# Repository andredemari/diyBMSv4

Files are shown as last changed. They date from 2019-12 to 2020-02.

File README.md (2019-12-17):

# ESP32 port of diyBMS v4

This is my port of Stuart Pittaway's excellent diyBMS ver 4 project

In this port the ESP8266 Controller has been replaced by an ESP32 and various changes have been made to support my local needs.
If you are looking for a straight port to ESP32 of Stuart's project, check out the 'Vanilla' branch.
Note: Because of the way serial ports work in ESP32, the Cell module firmware from this fork must be used. Cell modules programmed with the original firmware will not work.

Main changes are :-
* New Controller PCB design with ESP32 module ( a Lolin 32 Lite easily available on AliExpress)
* INA226 Current and Voltage monitor on PCB - INA226 is able to measure current through an external shunt on high or low side of battery. It supports battery voltages of up to 36V,
so since my battery is more than that I put the shunt halfway up the battery stack, and use a voltage divider to measure total battery voltage. INA226 is I2C connected to the ESP32.
https://www.ti.com/lit/ds/symlink/ina226.pdf
* I2C connector to attach to various fan controllers.
* PWM connector to signal discharge rate to my inverter.
* Serial interface to signal charge rate to my BST900 charger [BST900(https://github.com/delboy711/BST900)]
* Two connectors for Solid State Relays to power on/off charger and inverter.
* Management of Controller via MQTT commands from Node-Red.

Stuart's original README follows

##################################################################
 
Version 4 of the diyBMS

Do it yourself battery management system for Lithium ion battery packs/cells

If you are looking for version 3 of this project take a look here https://github.com/stuartpittaway/diyBMS

# TRAVIS-CI


# Videos on how to use and build

https://www.youtube.com/stuartpittaway

# WARNING

This is a DIY product/solution so don’t use this for safety critical systems or in any situation where there could be a risk to life.  

There is no warranty, it may not work as expected or at all.

The use of this project is done so entirely at your own risk.  It may involve electrical voltages which could kill - if in doubt, seek help.

The use of this project may not be compliant with local laws or regulations - if in doubt, seek help.

# License

This work is licensed under a Creative Commons Attribution-NonCommercial-ShareAlike 2.0 UK: England & Wales License.

https://creativecommons.org/licenses/by-nc-sa/2.0/uk/

You are free to:
* Share — copy and redistribute the material in any medium or format
* Adapt — remix, transform, and build upon the material
The licensor cannot revoke these freedoms as long as you follow the license terms.

Under the following terms:
* Attribution — You must give appropriate credit, provide a link to the license, and indicate if changes were made. You may do so in any reasonable manner, but not in any way that suggests the licensor endorses you or your use.
* Non-Commercial — You may not use the material for commercial purposes.
* ShareAlike — If you remix, transform, or build upon the material, you must distribute your contributions under the same license as the original.
* No additional restrictions — You may not apply legal terms or technological measures that legally restrict others from doing anything the license permits.

Notices:
You do not have to comply with the license for elements of the material in the public domain or where your use is permitted by an applicable exception or limitation.

No warranties are given. The license may not give you all of the permissions necessary for your intended use. For example, other rights such as publicity, privacy, or moral rights may limit how you use the material.

# Problem

A DIY Powerwall is the DIY construction of a pack of battery cells to create an energy store which can be used via inverters to power electrical items in the home. Generally cells are salvaged/second hand, and typically use Lithium 18650 cells.

Lithium batteries need to be kept at the same voltage level across a parallel pack. This is done by balancing each cell in the pack to raise or lower its voltage to match the others.

Existing balancing solutions are available in the market place, but at a relatively high cost compared to the cost of the battery bank, so this project is to design a low-cost, simple featured BMS/balancer.

# BMS Design

Design Goals: 
* Build upon my existing skill set and knowledge. 
* Building something that others can contribute to using regular standard libraries and off the shelf components.
* Build something that is inheriently safe
* Use platform.io to manage code and libraries
* Use Arduino based libraries and tools 
* Put everything on GITHUB
* Document it (always gets left to the end!)

# How it works

Controller provides human interface over Wifi/Web and also integrates with other systems like MQTT, emonCMS and Grafana.

Controller is esp8266-12e (NodeMCU v1) - although could be upgraded to ESP32 if really needed.

Controller should be able to take action on alerts/events to shut down inverters/chargers/fuses.

Each cell in a battery pack has a monitoring module.  This uses AVR ATTINY841 linked together by optoisolated serial ports for communication.

ATTINY841 provides:
* internal temperature monitoring
* external temperature monitoring
* Spare input/output for 3rd party use
* autonomous cell voltage balancing - it should still work even if controller is down

# How as v4 improved over v3?

* Code is better!
* Web interface no longer requires access to internet to download javascript libraries
* Controller provides outputs for integration with relay boards and switch gear
* Rules to control relay outputs
* Cell modules use ATTINY841 chip which provides more pins and lower power usage
* Removal of 3.3v regulator and ADUM chips lowers current usage significantly
* v3 module uses 10-12mA current constantly and v4 uses <1mA
* Dual temperature monitoring board + cells

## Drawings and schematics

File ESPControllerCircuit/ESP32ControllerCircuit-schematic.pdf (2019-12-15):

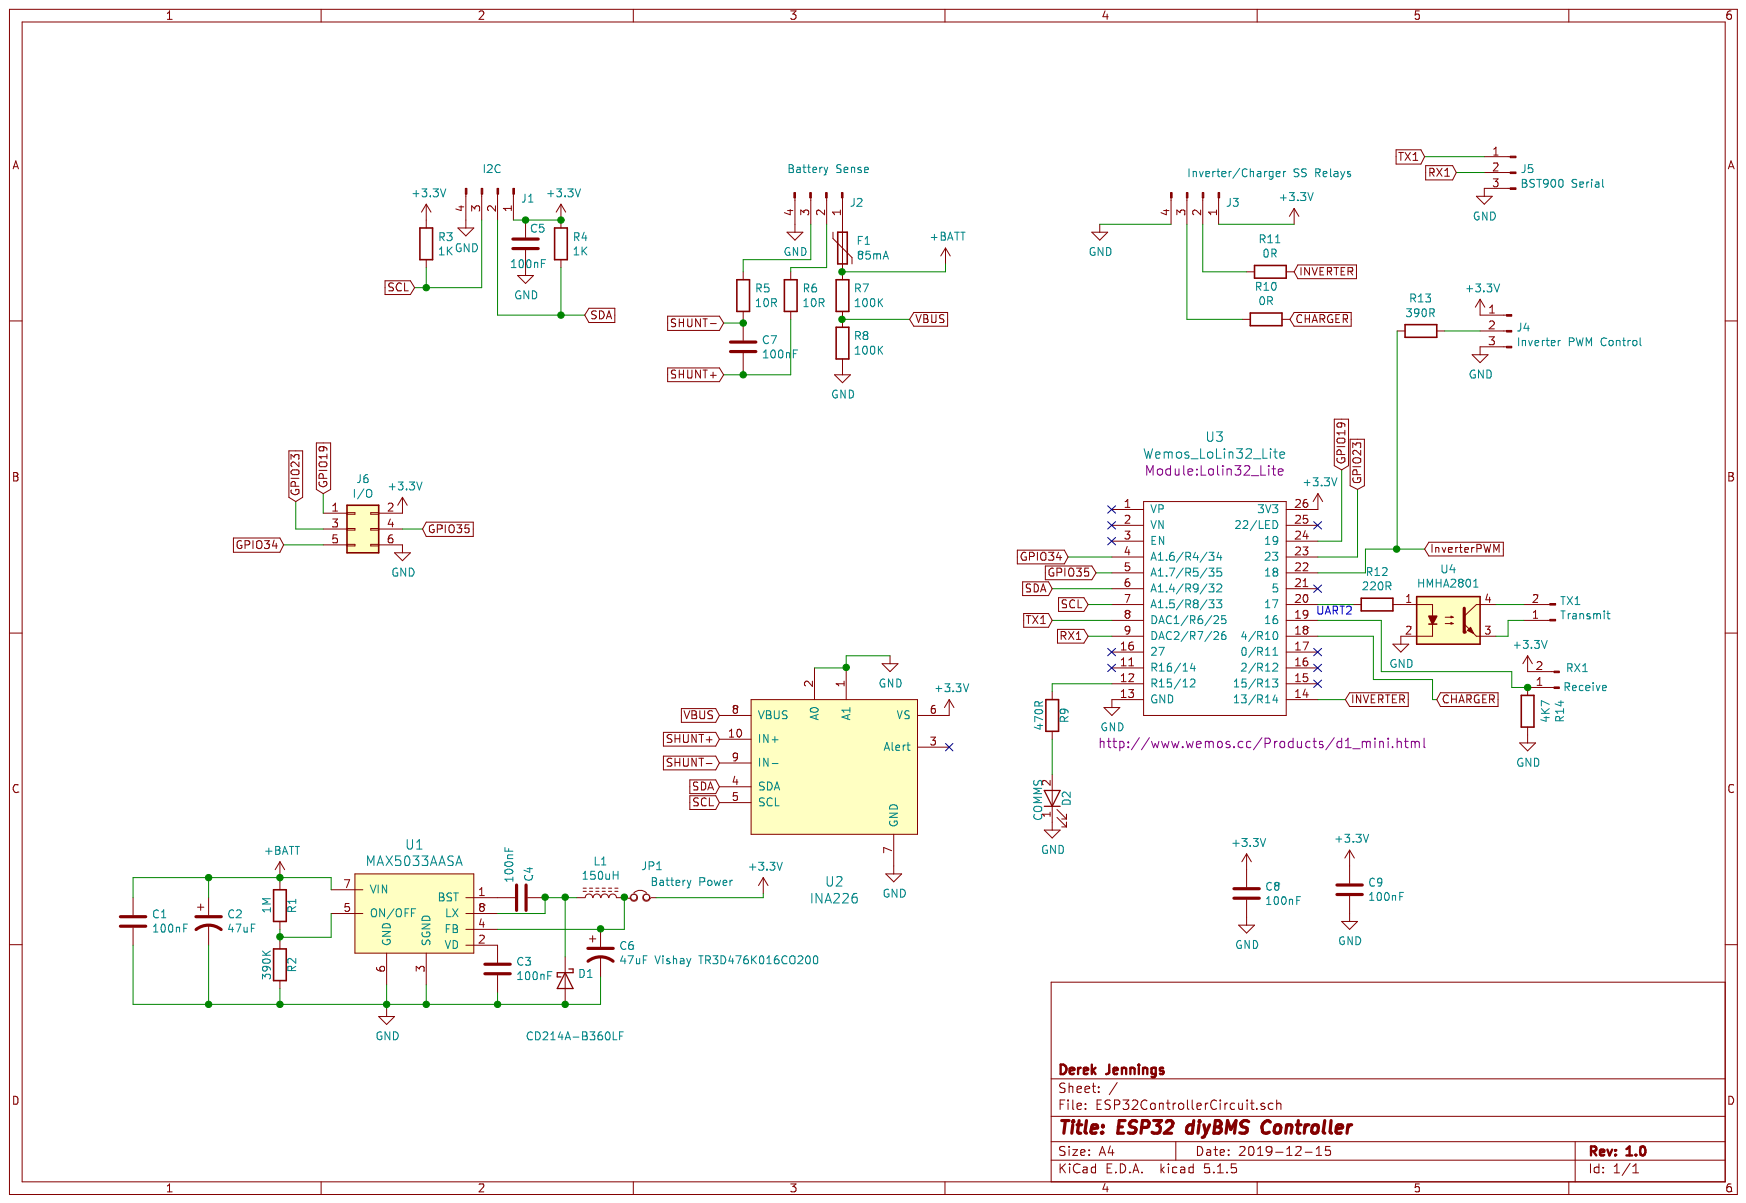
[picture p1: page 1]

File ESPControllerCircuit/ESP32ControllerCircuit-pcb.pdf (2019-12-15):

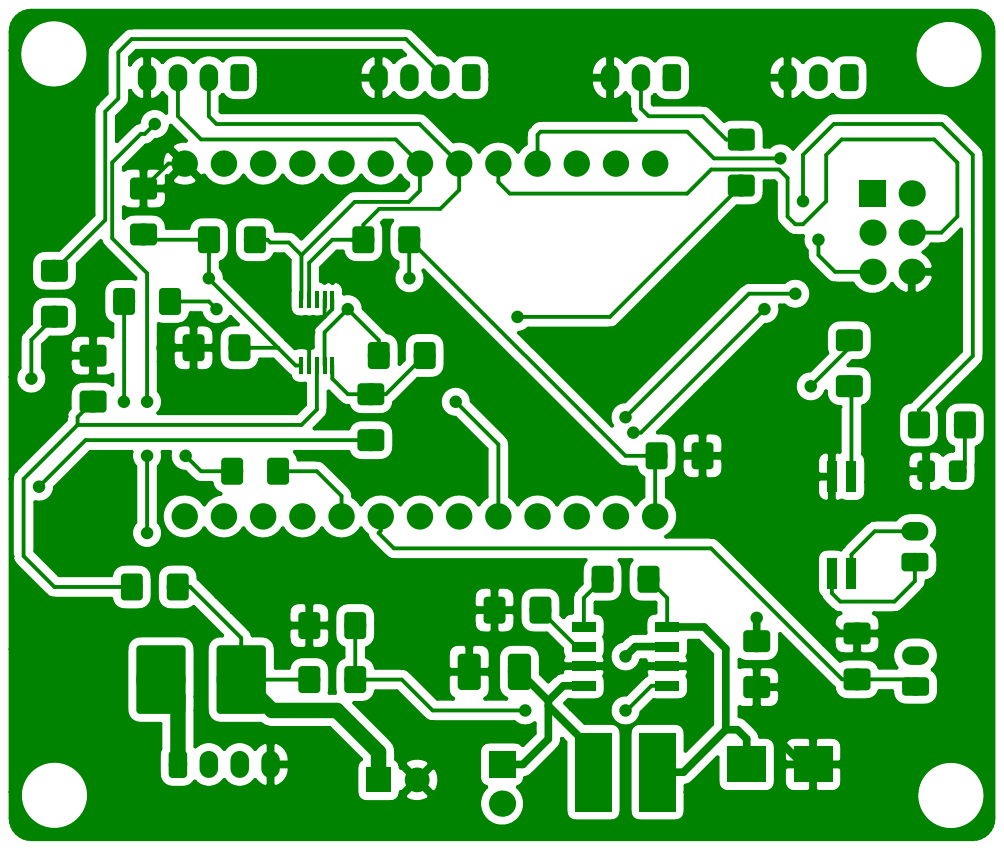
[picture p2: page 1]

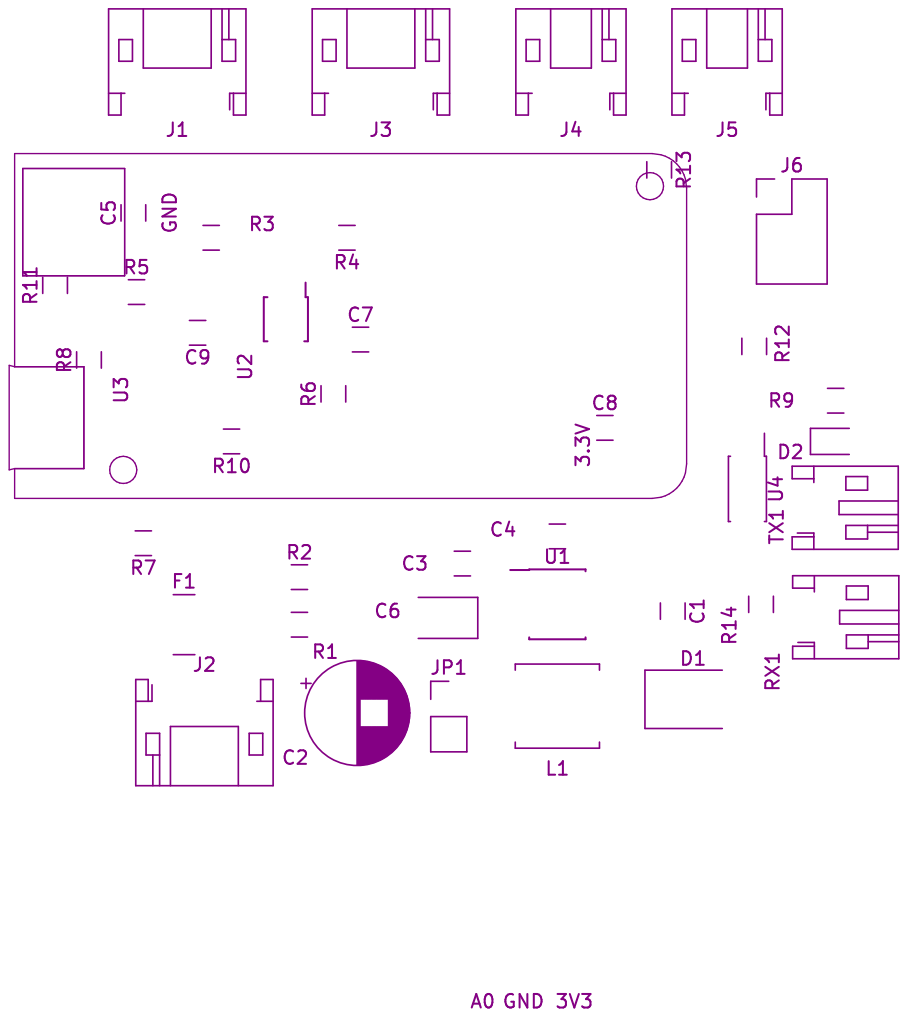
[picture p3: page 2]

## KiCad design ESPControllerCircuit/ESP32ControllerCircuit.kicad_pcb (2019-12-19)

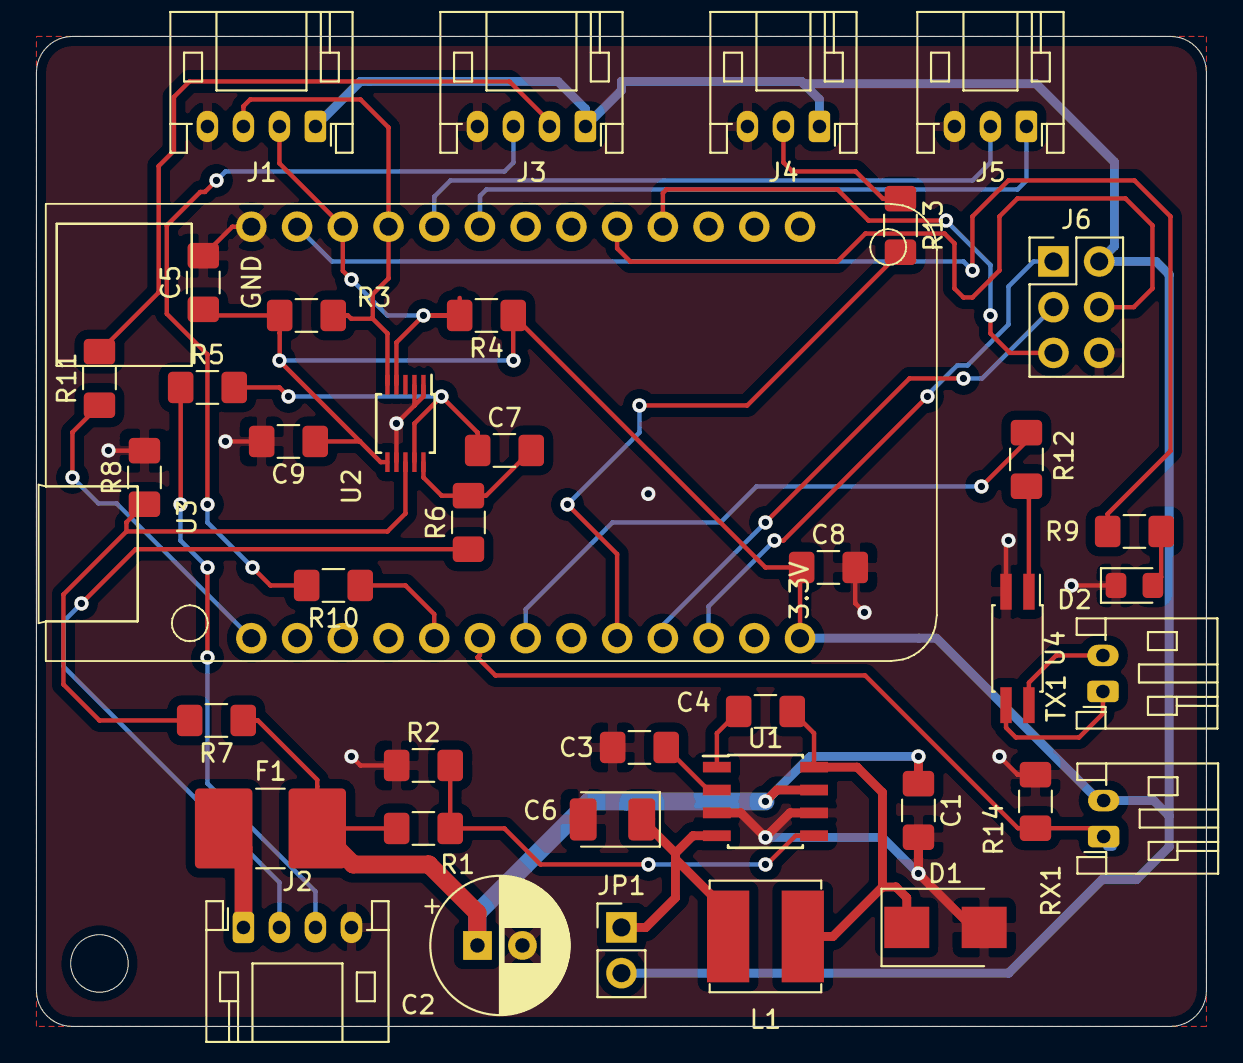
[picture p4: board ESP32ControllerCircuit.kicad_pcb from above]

Board: 2 copper layers, 65.0 x 55.0 mm, 40 parts (0 on the bottom side), 35 nets.

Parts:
C1, C3, C4, C5, C7, C8, C9: 100nF; C_1206_3216Metric_Pad1.42x1.75mm_HandSolder
C2: 47uF; CP_Radial_D7.5mm_P2.50mm
C6: 47uF Vishay TR3D476K016CO200; CP_EIA-3528-12_Kemet-T_Pad1.50x2.35mm_HandSolder
D1: CD214A-B360LF; D_SMB
D2: COMMS; LED_0805_2012Metric_Pad1.15x1.40mm_HandSolder
F1: 85mA; R_2816_7142Metric_Pad3.20x4.45mm_HandSolder
J1: I2C; JST_PH_S4B-PH-K_1x04_P2.00mm_Horizontal
J2: Battery Sense; JST_PH_S4B-PH-K_1x04_P2.00mm_Horizontal
J3: Inverter/Charger SS Relays; JST_PH_S4B-PH-K_1x04_P2.00mm_Horizontal
J4: Inverter PWM Control; JST_PH_S3B-PH-K_1x03_P2.00mm_Horizontal
J5: BST900 Serial; JST_PH_S3B-PH-K_1x03_P2.00mm_Horizontal
J6: I/O; PinHeader_2x03_P2.54mm_Vertical
JP1: Battery Power; PinHeader_1x02_P2.54mm_Vertical
L1: 150uH; L_Bourns_SRN6045TA
R1: 1M; R_1206_3216Metric_Pad1.42x1.75mm_HandSolder
R2: 390K; R_1206_3216Metric_Pad1.42x1.75mm_HandSolder
R3, R4: 1K; R_1206_3216Metric_Pad1.42x1.75mm_HandSolder
R5, R6: 10R; R_1206_3216Metric_Pad1.42x1.75mm_HandSolder
R7, R8: 100K; R_1206_3216Metric_Pad1.42x1.75mm_HandSolder
R9: 470R; R_1206_3216Metric_Pad1.42x1.75mm_HandSolder
R10, R11: 0R; R_1206_3216Metric_Pad1.42x1.75mm_HandSolder
R12: 220R; R_1206_3216Metric_Pad1.42x1.75mm_HandSolder
R13: 390R; R_1206_3216Metric_Pad1.42x1.75mm_HandSolder
R14: 4K7; R_1206_3216Metric_Pad1.42x1.75mm_HandSolder
RX1: Receive; JST_PH_S2B-PH-K_1x02_P2.00mm_Horizontal
TX1: Transmit; JST_PH_S2B-PH-K_1x02_P2.00mm_Horizontal
U1: MAX5033AASA; SOIC-8_3.9x4.9mm_P1.27mm
U2: INA226; TSSOP-10_3x3mm_P0.5mm
U3: Wemos_LoLin32_Lite; Lolin32_Lite
U4: HMHA2801; SO-4_4.4x2.3mm_P1.27mm

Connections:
+3V3: C5.1, C8.1, C9.1, J1.1, J3.1, J4.1, J6.2, JP1.2, R3.1, R4.1, RX1.2, U2.6, U3.26
+BATT: C1.1, C2.1, F1.2, R1.2, R7.1, U1.7
CHARGER: R10.1, U3.18
GND: C1.2, C2.2, C3.2, C5.2, C6.2, C8.2, C9.2, D1.2, D2.1, J1.4, J2.4, J3.4, J4.3, J5.3, J6.6, R2.1, R8.2, R14.1, U1.3, U1.6, U2.1, U2.2, U2.7, U3.13, U4.2
GPIO19: J6.1, U3.24
GPIO23: J6.3, U3.23
GPIO34: J6.5, U3.4
GPIO35: J6.4, U3.5
INVERTER: R11.1, U3.14
InverterPWM: R13.2, U3.22
unnamed: C3.1, U1.2
unnamed: C4.1, D1.1, L1.1, U1.8
unnamed: C4.2, U1.1
unnamed: C6.1, JP1.1, L1.2, U1.4
unnamed: D2.2, R9.1
unnamed: F1.1, J2.1
unnamed: J2.2, R6.1
unnamed: J2.3, R5.1
unnamed: J3.2, R11.2
unnamed: J3.3, R10.2
unnamed: J4.2, R13.1
unnamed: R1.1, R2.2, U1.5
unnamed: R9.2, U3.12
unnamed: R12.1, U4.1
unnamed: R12.2, U3.20
unnamed: R14.2, RX1.1, U3.19
unnamed: TX1.1, U4.3
unnamed: TX1.2, U4.4
RX1: J5.2, U3.9
SCL: J1.3, R3.2, U2.5, U3.10
SDA: J1.2, R4.2, U2.4, U3.11
SHUNT+: C7.2, R6.2, U2.10
SHUNT-: C7.1, R5.2, U2.9
TX1: J5.1, U3.8
VBUS: R7.2, R8.1, U2.8

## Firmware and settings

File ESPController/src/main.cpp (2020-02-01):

/*

 ____  ____  _  _  ____  __  __  ___    _  _  __
(  _ \(_  _)( \/ )(  _ \(  \/  )/ __)  ( \/ )/. |
 )(_) )_)(_  \  /  ) _ < )    ( \__ \   \  /(_  _)
(____/(____) (__) (____/(_/\/\_)(___/    \/   (_)

  (c) 2017/18/19 Stuart Pittaway

  This is the code for the controller - it talks to the V4 cell modules over isolated serial bus

  This code runs on ESP-8266-12E (NODE MCU 1.0) and compiles with Arduino 1.8.5 environment
  Modified by Derek Jennings to run on ESP32 compiled on platformio


   PINS
   GREEN_LED  = ESP32 GPIO 12
   i2c SDA   = ESP32 GPIO 32
   i2c SCL   = ESP32 GPIO 33
   switch to ground (reset WIFI configuration on power up) = ESP32 GPIO 34
   Interrupt in from PCF8574  = ESP32 GPIO 35
   PWM output to inverter = ESP32 GPIO 18
   ESP32_RELAY1 (CHARGER) 4       //GPIO PINS of ESP32 Relay outputs
   ESP32_RELAY2 (INVERTER) 13
   ESP32_RELAY3 19      //On expansion header
   Serial 0 DEBUG
   Serial 1  Charger Controller
   Serial 2   To Cell Modules


   DIAGRAM
   https://www.hackster.io/Aritro/getting-started-with-esp-nodemcu-using-arduinoide-aa7267
*/


#include <Arduino.h>
//#include <ESP8266WiFi.h>
#include <WiFi.h>
//#include <ESP8266mDNS.h>
#include <ESPmDNS.h>
#include <Hash.h>
#include <ESPAsyncWebServer.h>
#include <AsyncMqttClient.h>
#include <PacketSerial.h>
#include <cppQueue.h>
#include <Ticker.h>
#include <pcf8574_esp.h>
#include <Wire.h>
#include <ArduinoOTA.h>
#include "mqtt.h"

//Debug flags for ntpclientlib
#define DBG_PORT Serial
#define DEBUG_NTPCLIENT

#include <TimeLib.h>
#include <NtpClientLib.h>

#include "defines.h"

bool PCF8574Enabled;
volatile bool emergencyStop=false;
bool rule_outcome[RELAY_RULES];

uint16_t ConfigHasChanged=0;
diybms_eeprom_settings mysettings;

AsyncWebServer server(80);

bool server_running=false;
bool wifiFirstConnected = false;
bool NTPsyncEventTriggered = false; // True if a time even has been triggered
NTPSyncEvent_t ntpEvent; // Last triggered event

uint8_t packetType=0;
uint8_t previousRelayState[RELAY_TOTAL];
bool previousRelayPulse[RELAY_TOTAL];

//PCF8574P has an i2c address of 0x38 instead of the normal 0x20
PCF857x pcf8574(0x38, &Wire);

//Map GPIO pins to relays
uint8_t ESP32_relays[RELAY_TOTAL] = {ESP32_RELAY1, ESP32_RELAY2, ESP32_RELAY3};
volatile bool PCFInterruptFlag = false;

void ICACHE_RAM_ATTR PCFInterrupt() {
  if ((pcf8574.read8() & B00010000)==0) {
      //Emergency Stop (J1) has triggered
      emergencyStop=true;
  }
}

//This large array holds all the information about the modules
//up to 4x16
CellModuleInfo cmi[maximum_bank_of_modules][maximum_cell_modules];
uint8_t numberOfModules[maximum_bank_of_modules];



#include "crc16.h"

#include "settings.h"
#include "SoftAP.h"
#include "DIYBMSServer.h"
#include "PacketRequestGenerator.h"
#include "PacketReceiveProcessor.h"

// Instantiate queue to hold packets ready for transmission
Queue	requestQueue(sizeof(packet), 16, FIFO);

PacketRequestGenerator prg=PacketRequestGenerator(&requestQueue);

PacketReceiveProcessor receiveProc=PacketReceiveProcessor();

#define framingmarker (uint8_t)0x00

PacketSerial_<COBS, framingmarker, 128> myPacketSerial;

mqttProc mqt;

volatile bool waitingForReply=false;

//WiFiEventHandler wifiConnectHandler;
//WiFiEventHandler wifiDisconnectHandler;

Ticker myTimerRelay;

Ticker myTimer;
Ticker myTransmitTimer;
Ticker wifiReconnectTimer;
Ticker mqttReconnectTimer;
Ticker myTimerSendMqttPacket;
Ticker myTimerSendInfluxdbPacket;

Ticker myTimerSwitchPulsedRelay;
Ticker mqttTimeout;         //Times out if mqtt communication lost with node-red

uint16_t sequence=0;

AsyncMqttClient mqttClient;

void dumpPacketToDebug(packet *buffer) {
  Serial.print(buffer->address,HEX);
  Serial.print('/');
  Serial.print(buffer->command,HEX);
  Serial.print('/');
  Serial.print(buffer->sequence,HEX);
  Serial.print('=');
  for (size_t i = 0; i < maximum_cell_modules; i++)
  {
    Serial.print(buffer->moduledata[i],HEX);
    Serial.print(" ");
  }
  Serial.print(" =");
  Serial.print(buffer->crc,HEX);
}

uint16_t minutesSinceMidnight() {
  return (hour() * 60) + minute();
}

void processSyncEvent (NTPSyncEvent_t ntpEvent) {
    if (ntpEvent < 0) {
        Serial.printf ("Time Sync error: %d\n", ntpEvent);
        if (ntpEvent == noResponse)
            Serial.println ("NTP server not reachable");
        else if (ntpEvent == invalidAddress)
            Serial.println ("Invalid NTP server address");
        else if (ntpEvent == errorSending)
            Serial.println ("Error sending request");
        else if (ntpEvent == responseError)
            Serial.println ("NTP response error");
    } else {
        if (ntpEvent == timeSyncd) {
            Serial.print ("Got NTP time: ");
            Serial.println (NTP.getTimeDateString (NTP.getLastNTPSync()));
        }
    }
}

void mqtlostcomms() {   //callback when mqtt timeout timer expires
  mqt.lostcomms();
}

void onPacketReceived(const uint8_t* receivebuffer, size_t len)
{
  //Note that this function gets called frequently with zero length packets
  //due to the way the modules operate

  if (len==sizeof(packet)) {
    // Process decoded incoming packet
    Serial.print("R:");
    dumpPacketToDebug((packet*)receivebuffer);

    if (!receiveProc.ProcessReply(receivebuffer,sequence)) {
      Serial.println("** FAILED PROCESS REPLY **");
    }

    //We received a packet (although may have been an error)
    waitingForReply=false;

    Serial.println();
  }
}

void timerTransmitCallback() {
  //Don't send another message until we have received reply from the last one
  //this slows the transmit process down a lot so potentially need to look at a better
  //way to do this and also keep track of missing messages replies for error tracking
  if (waitingForReply) {
    //Serial.print('E');Serial.print(receiveProc.commsError);

    //Increment the counter to watch for complete comms failures
    receiveProc.commsError++;

    //After 5 attempts give up and send another packet
    if (receiveProc.commsError>10) {
      waitingForReply=false;
      receiveProc.totalMissedPacketCount++;
    } else {
        return;
    }
  }

  //Called every second to transmit anything that remains in the transmit queue
  if (!requestQueue.isEmpty()) {
    packet transmitBuffer;

    GREEN_LED_ON;

    //Wake up the connected cell module from sleep
    Serial2.write(framingmarker);
    delay(10);

    requestQueue.pop(&transmitBuffer);
    sequence++;
    transmitBuffer.sequence=sequence;
    transmitBuffer.crc=CRC16::CalculateArray((uint8_t*)&transmitBuffer, sizeof(packet) - 2);
    myPacketSerial.send((byte*)&transmitBuffer, sizeof(transmitBuffer));

    waitingForReply=true;

    Serial.print("S:");
    dumpPacketToDebug(&transmitBuffer);

    Serial.print("/Q:");
    Serial.print(requestQueue.getCount());
    Serial.print(" # ");

    GREEN_LED_OFF;
  }
}

void ProcessRules() {

//Runs the rules and populates rule_outcome array with true/false for each rule

  uint32_t packvoltage[4];

  packvoltage[0]=0;
  packvoltage[1]=0;
  packvoltage[2]=0;
  packvoltage[3]=0;

  for (int8_t r = 0; r < RELAY_RULES; r++)
  {
    rule_outcome[r]=false;
  }

  //If we have a communications error
  if (emergencyStop) {
    rule_outcome[0]=true;
  }

  //If we have a communications error
  if (receiveProc.commsError > 2) {
    rule_outcome[1]=true;
  }

  //Loop through cells
  for (int8_t bank = 0; bank < mysettings.totalNumberOfBanks; bank++)
  {
    for (int8_t i = 0; i < numberOfModules[bank]; i++) {

      packvoltage[bank]+=cmi[bank][i].voltagemV;

      if (cmi[bank][i].voltagemV > mysettings.rulevalue[2]) {
          //Rule 2 - Individual cell over voltage
          rule_outcome[2]=true;
      }

      if (cmi[bank][i].voltagemV < mysettings.rulevalue[3]) {
          //Rule 3 - Individual cell under voltage (mV)
          rule_outcome[3]=true;
      }

      if ((cmi[bank][i].externalTemp!=-40) && (cmi[bank][i].externalTemp > mysettings.rulevalue[4])) {
          //Rule 4 - Individual cell over temperature (external probe)
          rule_outcome[4]=true;
      }
    }
  }

  //Combine the voltages if we need to
  if (mysettings.combinationParallel==false) {
    packvoltage[0]+=packvoltage[1]+packvoltage[2]+packvoltage[3];
    packvoltage[1]=0;
    packvoltage[2]=0;
    packvoltage[3]=0;
  }

  for (int8_t bank = 0; bank < mysettings.totalNumberOfBanks; bank++)
  {
    if (packvoltage[bank] > mysettings.rulevalue[5]) {
      //Rule 5 - Pack over voltage (mV)
      rule_outcome[5]=true;
    }

    if (packvoltage[bank] < mysettings.rulevalue[6]) {
      //Rule 6 - Pack under voltage (mV)
      rule_outcome[6]=true;
    }
  }

  rule_outcome[7]= mqt.mqttRelayControl;          //Status of MQTT control
  if(mqt.active) {
    mqttTimeout.detach();
    mqttTimeout.attach(120, mqtlostcomms);      //Reset the timeout
    mqt.active=false;   //clear the flag. It will be set again when another command arrives
  }

  //Time based rules 8 and 9 (Rule 7 is MQTT)
  if (minutesSinceMidnight() >= mysettings.rulevalue[8]) {
    rule_outcome[8]=true;
  }
  if (minutesSinceMidnight() >= mysettings.rulevalue[9]) {
    rule_outcome[9]=true;
  }

}

void timerSwitchPulsedRelay() {
  //Set defaults based on configuration
  for (int8_t y = 0; y<RELAY_TOTAL; y++)
  {
    if (previousRelayPulse[y]) {
        //We now need to rapidly turn off the relay after a fixed period of time (pulse mode)
        //However we leave the relay and previousRelayState looking like the relay has triggered (it has!)
        //to prevent multiple pulses being sent on each rule refresh
        if(PCF8574Enabled) pcf8574.write(y, previousRelayState[y]==HIGH ? LOW:HIGH);
          else digitalWrite(ESP32_relays[y], previousRelayState[y]==HIGH ? LOW:HIGH);

      previousRelayPulse[y]=false;
    }
  }

  //This only fires once
  myTimerSwitchPulsedRelay.detach();
}


void timerProcessRules() {

  //Run the rules
  ProcessRules();

  // DO NOTE: When you write LOW to a pin on a PCF8574 it becomes an OUTPUT.
  // It wouldn't generate an interrupt if you were to connect a button to it that pulls it HIGH when you press the button.
  // Any pin you wish to use as input must be written HIGH and be pulled LOW to generate an interrupt.

  Serial.print("Rules:");
  for (int8_t r = 0; r < RELAY_RULES; r++)
  {
    Serial.print(rule_outcome[r]);
  }
  Serial.print(" = ");

  uint8_t relay[RELAY_TOTAL];

  //Set defaults based on configuration
  for (int8_t y = 0; y<RELAY_TOTAL; y++)
  {
    if(PCF8574Enabled) relay[y]=  mysettings.rulerelaydefault[y]==RELAY_ON ? LOW:HIGH;    //Inverse logic
    else relay[y]=  mysettings.rulerelaydefault[y]==RELAY_ON ? HIGH:LOW;
  }

  //Test the rules (in reverse order)
  for (int8_t n = RELAY_RULES-1; n>=0; n--)
  {

    if (rule_outcome[n]==true) {

      for (int8_t y = 0; y<RELAY_TOTAL; y++)
      {
        if (n==7) {         //MQTT rule
          relay[y] = mqt.mqttRelay[y];      //Set relays
          continue;
        }
        //Dont change relay if its set to ignore/X
        if (mysettings.rulerelaystate[n][y]!=RELAY_X) {
            //Logic is inverted on the PCF chip
            if (mysettings.rulerelaystate[n][y]==RELAY_ON) {
              relay[y]=(PCF8574Enabled) ? LOW : HIGH;     //Inverse logic if PCF8574 is fitted
            } else {
              relay[y]=(PCF8574Enabled) ? HIGH : LOW;
            }
        }
      }
    }
  }

  for (int8_t n = 0; n<RELAY_TOTAL; n++) {  //1st pass disable relays   (bit of a kludge)
    if (relay[n] == 0 ) digitalWrite(ESP32_relays[n], relay[n]);    //Ensure relays are never on at sane time
  }
  delay(100);
  char M;
  char changestatus[3] = {' ', ' ', ' '};
  char value[64];
  for (int8_t n = 0; n<RELAY_TOTAL; n++)    //2nd pass enable relays
  {
    M = (mqt.mqttRelayControl) ? 'M' : ' ';        //Indicate MQTT has control
    if (previousRelayState[n]!=relay[n]) {
      //Would be better here to use the WRITE8 to lower i2c traffic
      changestatus[n] = 'C';
      //Set the relay
      if (PCF8574Enabled) pcf8574.write(n, relay[n]);
        else {    //If PFC8574 not fitted use ESP32 pins instead
          digitalWrite(ESP32_relays[n], relay[n]);
        }
      previousRelayState[n]=relay[n];

      if (mysettings.relaytype[n]==RELAY_PULSE) {
        //If its a pulsed relay, invert the output quickly via a one time only timer
        previousRelayPulse[n]=true;
        myTimerSwitchPulsedRelay.attach(0.1, timerSwitchPulsedRelay);
      }
    }
  }
  sprintf(value, "Relay 0 %c = %d %c   Relay 1 %c = %d %c  Relay 2 %c = %d %c", \
    M, relay[0], changestatus[0], M, relay[1], changestatus[1],  M, relay[2], changestatus[2] );
  //mqttClient.publish("diybmsdebug", 0, true, value, strlen(value));
  Serial.println(value);
}

uint8_t counter=0;

void timerEnqueueCallback() {
  //this is called regularly on a timer, it determines what request to make to the modules (via the request queue)
  for (uint8_t b = 0; b < mysettings.totalNumberOfBanks; b++)
  {
    prg.sendCellVoltageRequest(b);
    prg.sendCellTemperatureRequest(b);

    //Every 50 loops also ask for bad packet count (saves battery power if we dont ask for this all the time)
    if (counter % 50==0) {
      prg.sendReadBadPacketCounter(b);
    }
  }

  //Its an unsigned byte, let it overflow to reset
  counter++;
}


void connectToWifi() {
  Serial.println("Connecting to Wi-Fi...");
  WiFi.mode(WIFI_STA);
  WiFi.begin(DIYBMSSoftAP::WifiSSID(), DIYBMSSoftAP::WifiPassword());
}


void connectToMqtt() {
  Serial.println("Connecting to MQTT...");
  mqttClient.connect();
}

static AsyncClient * aClient = NULL;

void setupInfluxClient()
{

    if (aClient) //client already exists
        return;

    aClient = new AsyncClient();
    if (!aClient) //could not allocate client
        return;

    aClient->onError([](void* arg, AsyncClient* client, err_t error) {
        Serial.println("Connect Error");
        aClient = NULL;
        delete client;
    }, NULL);

    aClient->onConnect([](void* arg, AsyncClient* client) {
        Serial.println("Connected");

        //Send the packet here

        aClient->onError(NULL, NULL);

        client->onDisconnect([](void* arg, AsyncClient* c) {
            Serial.println("Disconnected");
            aClient = NULL;
            delete c;
        }, NULL);

        client->onData([](void* arg, AsyncClient* c, void* data, size_t len) {
            //Data received
            Serial.print("\r\nData: ");Serial.println(len);
            //uint8_t* d = (uint8_t*)data;
            //for (size_t i = 0; i < len; i++) {Serial.write(d[i]);}
        }, NULL);

        //send the request

        //Construct URL for the influxdb
        //See API at https://docs.influxdata.com/influxdb/v1.7/tools/api/#write-http-endpoint

        String poststring;

        for (uint8_t bank = 0; bank < 4; bank++) {
         //TODO: We should send a request per bank not just a single POST as we are likely to exceed capabilities of ESP
          for (uint8_t i = 0; i < numberOfModules[bank]; i++) {

            //Data in LINE PROTOCOL format https://docs.influxdata.com/influxdb/v1.7/write_protocols/line_protocol_tutorial/
            poststring = poststring
                + "cells,"
                +"cell=" + String(bank+1)+"_"+String(i+1)
                + " v=" + String((float)cmi[bank][i].voltagemV/1000.0,3)
                + ",i=" + String(cmi[bank][i].internalTemp)+"i"
                + ",e=" + String(cmi[bank][i].externalTemp)+"i"
                + ",b=" + (cmi[bank][i].inBypass ? String("true"):String("false"))
                + "\n";
          }
        }

        //TODO: Need to URLEncode these values
        //+ String(mysettings.influxdb_host) + ":" + String(mysettings.influxdb_httpPort)
        String url = "/write?db=" + String(mysettings.influxdb_database)
            +"&u=" + String(mysettings.influxdb_user)
            +"&p=" + String(mysettings.influxdb_password);

        String header="POST "+url+" HTTP/1.1\r\n"
        +"Host: "+String(mysettings.influxdb_host)+"\r\n"
        +"Connection: close\r\n"
        +"Content-Length: "+poststring.length()+"\r\n"
        +"Content-Type: text/plain\r\n"
        +"\r\n";

        Serial.println(header.c_str());
        Serial.println(poststring.c_str());

        client->write(header.c_str());
        client->write(poststring.c_str());

    }, NULL);
}

void SendInfluxdbPacket() {
  if (!mysettings.influxdb_enabled) return;

  Serial.println("SendInfluxdbPacket");

  setupInfluxClient();

  if(!aClient->connect(mysettings.influxdb_host, mysettings.influxdb_httpPort )){
    Serial.println("Influxdb connect fail");
    AsyncClient * client = aClient;
    aClient = NULL;
    delete client;
  }
}


void startTimerToInfluxdb() {
  myTimerSendInfluxdbPacket.attach(30, SendInfluxdbPacket);
}

void onWifiConnect(WiFiEvent_t event, WiFiEventInfo_t info) {     // for esp32

  wifiFirstConnected = true;
  Serial.println("Connected to Wi-Fi.");
  Serial.print(F(". Connected IP:"));
  Serial.println(WiFi.localIP());

  if (!server_running)
  {
    DIYBMSServer::StartServer(&server);
    server_running=true;
  }

  if (mysettings.mqtt_enabled) {
    connectToMqtt();
  }

  if (mysettings.influxdb_enabled) {
    startTimerToInfluxdb();
  }

  MDNS.begin(HOSTNAME);          //Start mDNS
  MDNS.addService("http", "tcp", 80);
}


void onWifiDisconnect(WiFiEvent_t event, WiFiEventInfo_t info) {    // for esp32
  Serial.println("Disconnected from Wi-Fi.");

  // ensure we don't reconnect to MQTT while reconnecting to Wi-Fi
  mqttReconnectTimer.detach();
  myTimerSendMqttPacket.detach();
  myTimerSendInfluxdbPacket.detach();

  wifiReconnectTimer.once(2, connectToWifi);

  //DIYBMSServer::StopServer(&server);
  //server_running=false;
}

void onMqttDisconnect(AsyncMqttClientDisconnectReason reason) {
  Serial.println("Disconnected from MQTT.");

  myTimerSendMqttPacket.detach();

  if (WiFi.isConnected()) {
    mqttReconnectTimer.once(2, connectToMqtt);
  }
}

void sendMqttPacket() {
  if (!mysettings.mqtt_enabled) return;

  Serial.println("Sending MQTT");
  for (uint8_t bank = 0; bank < 4; bank++) {
    for (uint8_t i = 0; i < numberOfModules[bank]; i++) {
      mqt.sendModuleStatus(bank, i);
    }
  }
  mqt.updatebus();    //Send Bus voltage/current
}

void onMqttConnect(bool sessionPresent) {
  Serial.println("Connected to MQTT.");
  mqttClient.subscribe("diybms_command", 0);
  myTimerSendMqttPacket.attach(20, sendMqttPacket);
}

void onMqttMessage(char* topic, char* payload, AsyncMqttClientMessageProperties properties, size_t len, size_t index, size_t total) {
  mqt.processCommand(payload,len);
}
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
void loop() {
  ArduinoOTA.handle();

  // Call update to receive, decode and process incoming packets.
  if (Serial2.available()) {
    myPacketSerial.update();
  }

  if (Serial1.available()) mqt.bst_process();    //Data has arrived on serial interface from boost converter

  if (ConfigHasChanged>0) {
      //Auto reboot if needed (after changing MQTT or INFLUX settings)
      //Ideally we wouldn't need to reboot if the code could sort itself out!
      ConfigHasChanged--;
      if (ConfigHasChanged==0) {
        Serial.println("RESTART AFTER CONFIG CHANGE");
        //Stop networking
        if (mqttClient.connected()) {
          mqttClient.disconnect(true);
        }
        WiFi.disconnect();
        ESP.restart();
      }
      delay(1);
  }

  //if (emergencyStop) {    Serial.println("EMERGENCY STOP");  }

  if (wifiFirstConnected) {
      Serial.print("Requesting NTP from ");
      Serial.println(mysettings.ntpServer);
      wifiFirstConnected = false;
      //Update time every 10 minutes
      NTP.setInterval (600);
      NTP.setNTPTimeout (NTP_TIMEOUT);
      // String ntpServerName, int8_t timeZone, bool daylight, int8_t minutes, AsyncUDP* udp_conn
      NTP.begin (mysettings.ntpServer, mysettings.timeZone, mysettings.daylight, mysettings.minutesTimeZone);
  }

  if (NTPsyncEventTriggered) {
      processSyncEvent (ntpEvent);
      NTPsyncEventTriggered = false;
  }
}

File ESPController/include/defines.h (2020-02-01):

#include <Arduino.h>

#ifndef DIYBMS_DEFINES_H_
#define DIYBMS_DEFINES_H_

#define GREEN_LED 12    //GPIO 12

#define SDA 14    //I2C pins
#define SCL 27
#define CLEARAPSETTINGS 23      //Pin on expansion header

#define GREEN_LED_ON digitalWrite(GREEN_LED,HIGH)
#define GREEN_LED_OFF digitalWrite(GREEN_LED,LOW)

#define RELAY_ON 0xFF
#define RELAY_OFF 0x99
#define RELAY_X 0x00

//#define RELAY_RULES 9
#define RELAY_RULES 10        //Tenth rule for mqtt control
//Number of relays on board (4)
#define RELAY_TOTAL 3         //ESP32 has 2 relay outputs by default + 1 on expansion header
#define ESP32_RELAY1 4       //GPIO PINS of ESP32 Relay outputs
#define CHARGER 4            //Alternative name
#define ESP32_RELAY2 13
#define INVERTER 13           //Alternative name
#define ESP32_RELAY3 19       //Pin on expansion header
#define INVERTER_PWM 18       //To control inverter output
#define MAXCHARGERATE 12.0      //Maximum rate of charger in Amps
#define MAXDISCHARGE 170      //Max Inverter PWM output
#define SHUNT 1500            //Define shunt resistance in micro ohms

#define RELAY_STANDARD 0x00
#define RELAY_PULSE 0x01

#define SHOW_TIME_PERIOD 5000
#define NTP_TIMEOUT 1500

#define HOSTNAME "diybmsv4"
#define MQTTSUBJECT "diybmsv4"



struct diybms_eeprom_settings {
  bool combinationParallel;
  uint8_t totalNumberOfBanks;

  uint16_t rulevalue[RELAY_RULES];

  //Use a bit pattern to indicate the relay states
  uint8_t rulerelaystate[RELAY_RULES][RELAY_TOTAL];
  //Default starting state
  uint8_t rulerelaydefault[RELAY_TOTAL];
  //Default starting state for relay types
  uint8_t relaytype[RELAY_TOTAL];

  int8_t timeZone;// = 0;
  int8_t minutesTimeZone;// = 0;
  bool daylight;//=false;
  char ntpServer[64+1];// = "time.google.com";


  //NOTE this array is subject to buffer overflow vulnerabilities!
  bool mqtt_enabled;
  uint16_t mqtt_port;
  char mqtt_server[64+1];
  char mqtt_username[32+1];
  char mqtt_password[32+1];

  bool influxdb_enabled;
  uint16_t influxdb_httpPort;
  char influxdb_host[64 +1];
  char influxdb_database[32 + 1];
  char influxdb_user[32 + 1];
  char influxdb_password[32 + 1];
};


typedef union
{
 float number;
 uint8_t bytes[4];
 uint16_t word[2];
} FLOATUNION_t;

enum COMMAND: uint8_t
{
    SetBankIdentity=B00000000,
    ReadVoltageAndStatus=B00000001,
    Identify=B00000010,
    ReadTemperature=B00000011,
    ReadBadPacketCounter=B00000100,
    ReadSettings=B00000101,
    WriteSettings=B00000110,
    VolatileSettings=B00000111

    // 0000 0000  = set bank identity
    // 0000 0001  = read voltage and status
    // 0000 0010  = identify module (flash leds)
    // 0000 0011  = Read temperature
    // 0000 0100  = Report number of bad packets
    // 0000 0101  = Report settings/configuration
    // 0000 0110  = Write settings and save to EEPROM
    // 0000 0111  = Write Settings, no save to EEPROM
};

//Maximum of 16 cell modules (dont change this!)
#define maximum_cell_modules 16
#define maximum_bank_of_modules 4

//NOTE THIS MUST BE EVEN IN SIZE (BYTES) ESP8266 IS 32 BIT AND WILL ALIGN AS SUCH!
struct packet {
  uint8_t address;
  uint8_t command;
  uint16_t sequence;
  uint16_t moduledata[maximum_cell_modules];
  uint16_t crc;
}  __attribute__((packed));

struct CellModuleInfo {
  //Used as part of the enquiry functions
  bool settingsCached;

  uint16_t voltagemV;
  uint16_t voltagemVMin;
  uint16_t voltagemVMax;
  //Signed integer - should these be byte?
  int8_t internalTemp;
  int8_t externalTemp;

  bool inBypass;
  bool bypassOverTemp;

  uint8_t BypassOverTempShutdown;
  uint16_t BypassThresholdmV;

  uint16_t badPacketCount;

  // Resistance of bypass load
  float LoadResistance;
  //Voltage Calibration
  float Calibration;
  //Reference voltage (millivolt) normally 2.00mV
  float mVPerADC;
  //Internal Thermistor settings
  uint16_t Internal_BCoefficient;
  //External Thermistor settings
  uint16_t External_BCoefficient;

};



//This holds all the cell information in a large array 2D array (4x16)
extern CellModuleInfo cmi[maximum_bank_of_modules][maximum_cell_modules];
extern uint8_t numberOfModules[maximum_bank_of_modules];

#endif

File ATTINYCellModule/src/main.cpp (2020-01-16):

/*
 ____  ____  _  _  ____  __  __  ___    _  _  __
(  _ \(_  _)( \/ )(  _ \(  \/  )/ __)  ( \/ )/. |
 )(_) )_)(_  \  /  ) _ < )    ( \__ \   \  /(_  _)
(____/(____) (__) (____/(_/\/\_)(___/    \/   (_)

DIYBMS V4.0
CELL MODULE FOR ATTINY841

(c)2019 Stuart Pittaway

COMPILE THIS CODE USING PLATFORM.IO

LICENSE
Attribution-NonCommercial-ShareAlike 2.0 UK: England & Wales (CC BY-NC-SA 2.0 UK)
https://creativecommons.org/licenses/by-nc-sa/2.0/uk/

* Non-Commercial — You may not use the material for commercial purposes.
* Attribution — You must give appropriate credit, provide a link to the license, and indicate if changes were made.
  You may do so in any reasonable manner, but not in any way that suggests the licensor endorses you or your use.
* ShareAlike — If you remix, transform, or build upon the material, you must distribute your
  contributions under the same license as the original.
* No additional restrictions — You may not apply legal terms or technological measures
  that legally restrict others from doing anything the license permits.
*/


#include <Arduino.h>

#if !(F_CPU == 8000000)
#error Processor speed should be 8 Mhz internal
#endif

//An Arduino Library that facilitates packet-based serial communication using COBS or SLIP encoding.
//https://github.com/bakercp/PacketSerial
#include <PacketSerial.h>

#define framingmarker (uint8_t)0x00

//Consistant byte stuffing mode
//Use ZERO for packet header/terminator
//64 byte buffer
PacketSerial_ <COBS, framingmarker, 64> myPacketSerial;

//Our project code includes
#include "defines.h"
#include "settings.h"
#include <FastPID.h>

#include "diybms_attiny841.h"
#include "packet_processor.h"

//Default values which get overwritten by EEPROM on power up
CellModuleConfig myConfig;

DiyBMSATTiny841 hardware;

PacketProcessor PP(&hardware, &myConfig);

volatile bool wdt_triggered = false;
uint16_t bypassCountDown = 0;
uint8_t bypassHasJustFinished = 0;

void DefaultConfig() {
  myConfig.LoadResistance = 4.40;

  //About 2.2100 seems about right
  myConfig.Calibration = 2.17000;

  //2mV per ADC resolution
  myConfig.mVPerADC = 2.0; //2048.0/1024.0;

  //Stop running bypass if temperature over 70 degrees C
  myConfig.BypassOverTempShutdown = 67;

  myConfig.mybank = 0;

  //Start bypass at 4.1 volt
  myConfig.BypassThresholdmV = 4050;

  //3960 = B constant (25-50℃)
  myConfig.Internal_BCoefficient = 3960;
  //3950 = B constant (25-50℃)
  myConfig.External_BCoefficient = 3950;

  // Resistance @ 25℃ = 47k, B Constant 4150, 0.20mA max current
  //Using https://www.thinksrs.com/downloads/programs/therm%20calc/ntccalibrator/ntccalculator.html
}

ISR(WDT_vect) {
  //This is the watchdog timer - something went wrong and no activity recieved in a while
  wdt_triggered = true;
  PP.IncrementWatchdogCounter();
}

ISR(ADC_vect) {
  // when ADC completed, take an interrupt and process result
  PP.ADCReading(hardware.ReadADC());
}

void onPacketReceived(const uint8_t* receivebuffer, size_t len) {

  if (len > 0) {

    //A data packet has just arrived, process it and forward the results to the next module
    if (PP.onPacketReceived(receivebuffer, len)) {
      //Only light green if packet is good
      hardware.GreenLedOn();
    }

    hardware.EnableSerial0TX();

    //Wake up the connected cell module from sleep, send a framingmarker
    //byte which the receiver will ignore
    Serial.write(framingmarker);
    //Let connected module wake up
    delay(8);

    //Send the packet (even if it was invalid so controller can count crc errors)
    myPacketSerial.send(PP.GetBufferPointer(), PP.GetBufferSize());

    //DEBUG: Are there any known issues with Serial Flush causing a CPU to hang?
    //hardware.FlushSerial0();

    //Replace flush with a simple delay - we have 35+ bytes to transmit at 4800 baud + COBS encoding
    delay(10);          //Necessary for ESP32

    hardware.DisableSerial0TX();
  }

  hardware.GreenLedOff();
}

ISR(USART0_START_vect) {
  //Needs to be here!
  asm("NOP");
}

//Kp: Determines how aggressively the PID reacts to the current amount of error (Proportional)
//Ki: Determines how aggressively the PID reacts to error over time (Integral)
//Kd: Determines how aggressively the PID reacts to the change in error (Derivative)

//6Hz rate - number of times we call this code in Loop
FastPID myPID(175.0, 3.5, 8, 6, 16, false);

void setup() {
  //Must be first line of code
  wdt_disable();
  wdt_reset();

  //8 second between watchdogs
  hardware.SetWatchdog8sec();

  //Setup IO ports
  hardware.ConfigurePorts();

  //More power saving changes
  hardware.EnableSerial0();

  hardware.DisableSerial1();

  //Check if setup routine needs to be run
  if (!Settings::ReadConfigFromEEPROM((uint8_t*)&myConfig, sizeof(myConfig), EEPROM_CONFIG_ADDRESS)) {
    DefaultConfig();
    //Save settings   - No need to save Default settings
    //Settings::WriteConfigToEEPROM((uint8_t*)&myConfig, sizeof(myConfig), EEPROM_CONFIG_ADDRESS);
  }

  hardware.double_tap_green_led();

  //Set up data handler
  Serial.begin(4800, SERIAL_8N1);

  myPacketSerial.setStream(&Serial);
  myPacketSerial.setPacketHandler(&onPacketReceived);

}

//bool hztiming=false;
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

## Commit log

2019-12-15 Port to ESP32
2019-12-15 Add command for volatile settings + fixes * Command added to write settings without save to EEPROM * Bugfix to prevent Out of Sequence Errors * PlatformIO upload using Arduino as ISP
    [defines.h, main.cpp, packet_processor.cpp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]
2019-12-15 Added ESP32 Circuit PCB
    [ESP32ControllerCircuit-B_Cu.gbr, ESP32ControllerCircuit-B_Mask.gbr, ESP32ControllerCircuit-B_Paste.gbr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]
2019-12-17 Relay Control by MQTT * More mqtt commands implemented * control of charging and discharging via mqtt
2019-12-17 Fix compiler warning errors about data types
    [main.cpp, packet_processor.cpp]
2019-12-17 Frame marker to zero
2019-12-17 Label Serial1 ports
    [v4.sch]
2019-12-17 Remove debug code and tweak PID settings
2019-12-17 Test program for PID calibration
2019-12-17 Reapply fix for communication with ESP32
    [main.cpp]
2019-12-19 use different pins for I2C
    [ESP32ControllerCircuit-B_Cu.gbr, ESP32ControllerCircuit-B_Mask.gbr, ESP32ControllerCircuit-B_Paste.gbr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]
2019-12-20 Add INA226 Voltage/Current/Power Sensor support * Partial implementation of home brew I2C PWM fan controller * Partial implementation of home brew I2C AC power monitor
2019-12-21 Replace EEPROM library with 'Preferences' library * There were issues with EEPROM corruption when resetting with push button.
    [DIYBMSServer.cpp, defines.h, main.cpp]
2020-01-16 Fix repeating packets bug
    [main.cpp, packet_processor.cpp]
2020-02-01 Add new relay rule for mqtt control
